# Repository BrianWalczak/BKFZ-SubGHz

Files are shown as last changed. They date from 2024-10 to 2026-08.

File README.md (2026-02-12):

<h1 align="center">BKFZ SubGHz</h1>
<p align="center">A robust program for your ESP32 to capture and replay SubGHz frequencies, inspired by the Flipper Zero and written in Arduino + React Native.</p>

<p align="center">
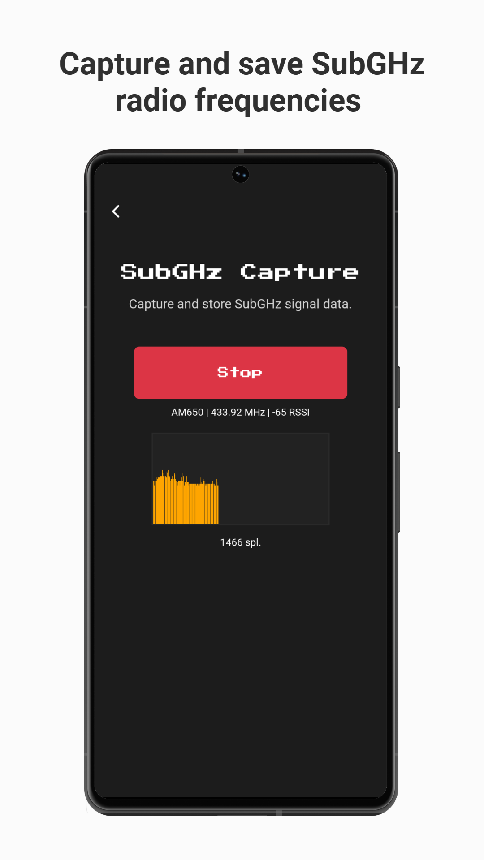
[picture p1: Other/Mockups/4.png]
  
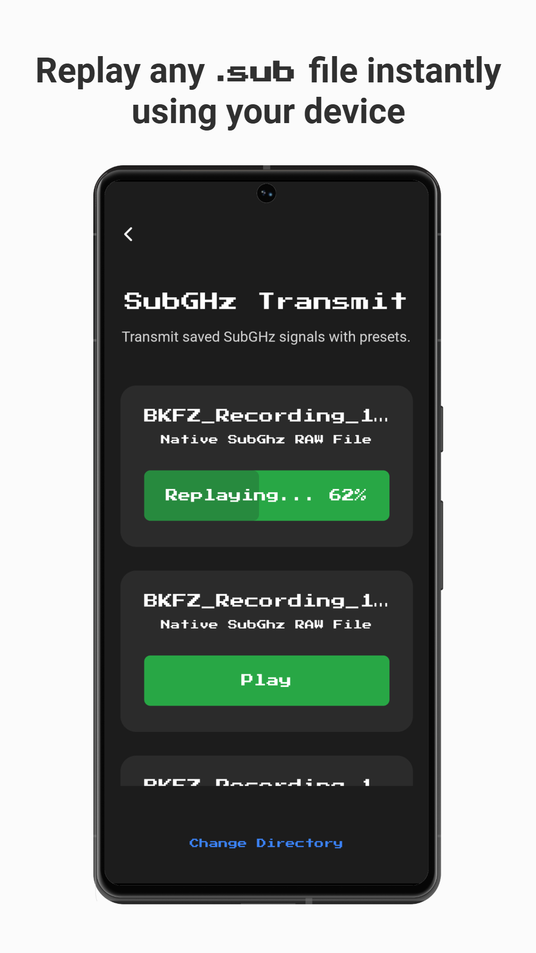
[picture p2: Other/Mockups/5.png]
  
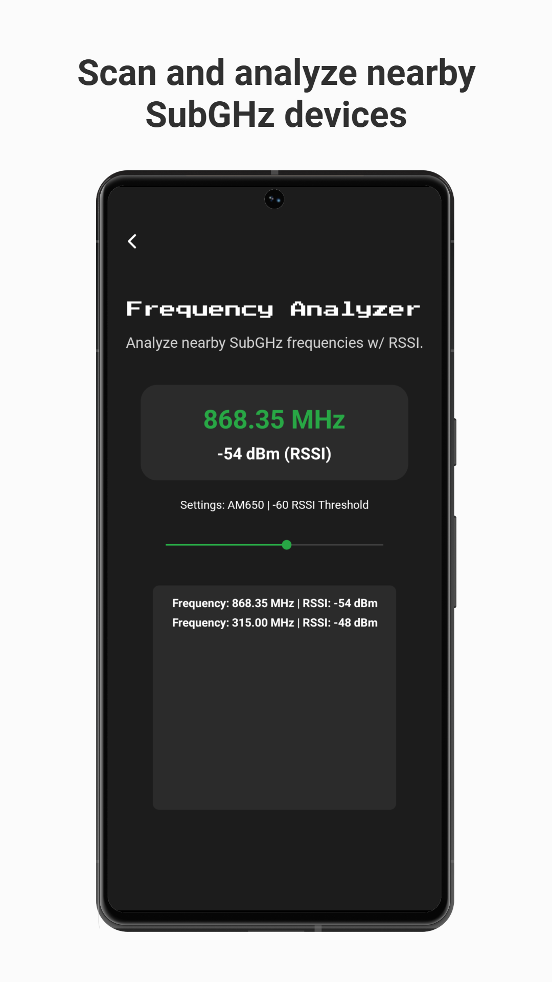
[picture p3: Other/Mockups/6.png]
  
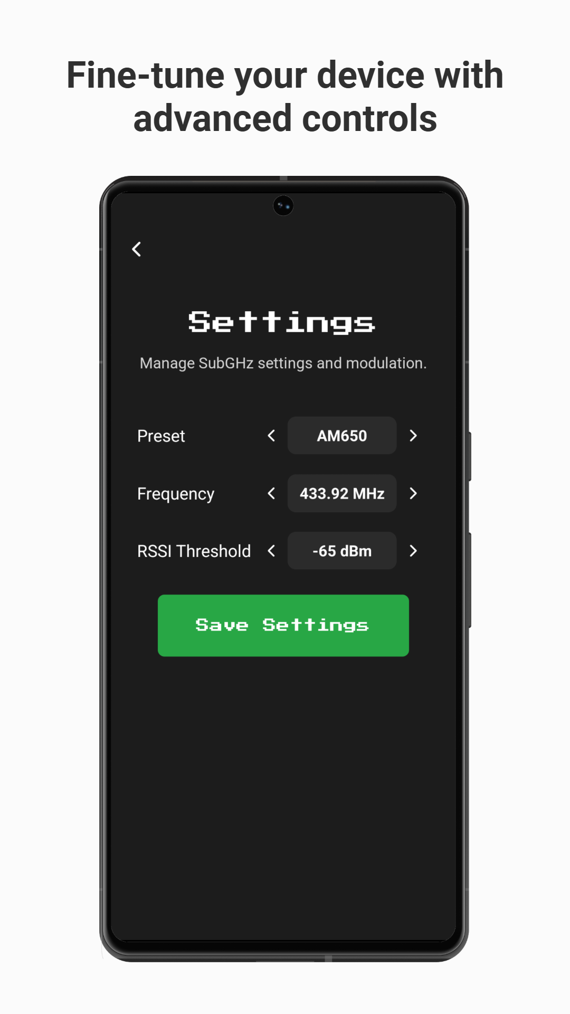
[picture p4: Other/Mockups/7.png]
  
</p>

> [!WARNING]
> **Heads up! Major changes have been made since the previous release. If you encounter any issues, please report them <a href='https://github.com/brianwalczak/BKFZ-SubGHz/issues'>here</a>.**

## Features
- (📻) **Record RAW** - Capture and save SubGHz radio frequencies with a configurable RSSI threshold (saved as `.sub`).
- (📡) **Replay/Emulate RAW** - Easily transmit SubGHz radio frequencies from file (no SD card required).
- (🔍) **Frequency Analyzer** - Scan and analyze nearby devices across multiple frequencies (300-928 MHz).
- (⚙️) **Custom Presets** - Support for various digital modulations and frequency bands with customizable presets.
- (🛜) **Wi-Fi/Bluetooth Connectivity** - Support for both Bluetooth and Wi-Fi based connectivity (web server).
    - (📱) **Mobile App** - Cross-platform mobile application for Bluetooth, powered by React Native (iOS + Android).
    - (🌐) **Web App** -  WebSocket-powered web app for Wi-Fi connectivity, works on any device with a browser.
- (🐬) **Flipper Zero Support** - Built with Flipper Zero native support, allowing you to record and play `.sub` files.
- (🔋) **Portable Design** - Custom PCB design for battery-powered operation with a compact design.
- (👤) **Open Source** Open-source under Apache 2.0 license - contribute or view it anytime.

## Requirements
To start, you'll need (by minimum) an [**ESP32**](https://s.click.aliexpress.com/e/_DCh9q31) [$2.97] of your choice and a [**CC1101 RF Transceiver**](https://s.click.aliexpress.com/e/_DlNeVmT) [$2.01]. You can purchase both of these parts in the links provided.

> [!CAUTION]
> **When choosing a CC1101 module, make sure to select the operating frequency that is most commonly used in your region. The** `433 MHz` **frequency band is generally most common, but this may vary based on the device you're attempting to emulate.<br><br>Your module can use either a [wire antenna](https://s.click.aliexpress.com/e/_DlNeVmT) or an [SMA antenna](https://s.click.aliexpress.com/e/_Dn4dKAr) — both options are compatible.**

If you're looking to build a fully-fledged BKFZ SubGHz device, you'll want to purchase these additional components (about **~$13.03**):
- [2000mAh Lithium Battery](https://s.click.aliexpress.com/e/_DnKGR3V): **$6.03** on AliExpress (**ensure your ESP32 includes a built-in voltage regulator, or attach one separately**)
- [TP4056 Module (5pk)](https://s.click.aliexpress.com/e/_Dd8V8J1): **$1.36** on AliExpress
- [Latching Buttons (10pk)](https://s.click.aliexpress.com/e/_DkSsHEL): **$1.13** on AliExpress 
- [JST 2mm Connectors (10pk)](https://s.click.aliexpress.com/e/_DCTEiy7): **$1.01** on AliExpress 
- [Custom PCB Print](https://github.com/brianwalczak/BKFZ-SubGHz/tree/main/KiCad_PCB#bkfz-subghz---kicad-pcb): **~$3.50** on JLCPCB (w/ shipping)
<br>
Assembly Parts

The custom PCB design, as found [here](https://github.com/brianwalczak/BKFZ-SubGHz/tree/main/KiCad_PCB#bkfz-subghz---kicad-pcb), is specifically designed to work with the 433 MHz module(s) linked above.

## Getting Started
To flash the BKFZ SubGHz program on your ESP32, you'll need to connect the CC1101 module first. By default, the following pinout is used:
| ESP32 | CC1101 |
|---|---|
| GND | GND |
| 3.3V | VCC |
| G5 | CSN |
| G13 | MOSI |
| G19 | MISO |
| G14 | SCK |
| G16 | GDO0 |
| G18 | GDO2 |

If you'd like to use a different pinout, you can configure the pins in the `headers/config.h` configuration file.

Additionally, **you'll need to decide which connection mode you'd like to use**. By default, your BKFZ SubGHz device will use Bluetooth Low Energy for communication with the **mobile app**. If you'd like to use Wi-Fi connectivity (or your device does not support the mobile app), you should modify the `CONNECTION_MODE` definition to `CONNECTION_MODE_WIFI` in the configuration file.

**Note:** If possible, Bluetooth connectivity is highly recommended as it's more reliable on mobile devices.

To install the BKFZ SubGHz firmware, you'll need to open this repository in Arduino IDE in the `Arduino/` folder.

---

### Wi-Fi Connection

If you've selected Wi-Fi as the connection mode, you'll need to download and install the [LittleFS Upload](https://github.com/earlephilhower/arduino-littlefs-upload) plugin (you can find instructions on installation in the repository). This plugin is crucial to serve essential files through the web server (CSS, fonts, icons, etc).

Next, you should upload the `data/` files through LittleFS (`Ctrl` + `Shift` + `P`, then `Upload LittleFS to Pico/ESP8266/ESP32`). **Make sure your Serial Monitor is closed during the uploading process.**

---

Lastly, click the `Upload` icon in the Arduino IDE to flash the code on your ESP32. All done!

## Usage
Once you've completed the firmware installation, it's time to access the interface! There are multiple ways to do this, depending on the connection mode you've selected.

### Bluetooth Connection

> [!WARNING]
> Currently, the BKFZ SubGHz mobile app must be sideloaded on your device while I work to publish it on the Google Play Store. Due to App Store restrictions, iOS devices will **always** require manual sideloading through Xcode. Please follow the instructions below to continue.

To access the user interface on a Bluetooth connection, you'll need to download the official **BKFZ SubGHz** app for iPhone or Android.

To compile the application manually, start by installing the required dependencies in this repository:
```bash
git clone https://github.com/brianwalczak/BKFZ-SubGHz.git
cd BKFZ-SubGHz/Application
npm install
```

Next, follow the instructions below based on your device's operating system:

#### iOS Devices
In order to sideload the application to your iPhone, you'll need to install Xcode [here](https://apps.apple.com/us/app/xcode/id497799835) on a Mac and login to an Apple ID (free or paid).

Next, you'll need to download Xcode Command Line Tools for compatibility with Expo:
```bash
xcode-select --install
```

Follow the instructions on your Mac to finish installation, then plug in your iOS device. To begin building the application, run this command:
```bash
npx expo run:ios --device --configuration Release
```

This process may take a few minutes, and the application will be installed to your device once complete. You may need to trust the developer on your iPhone to launch the application (`Settings > General > VPN & Device Management`, under `Developer App`).

#### Android Devices
There are two different ways you can install the BKFZ SubGHz app on your Android device.

- Visit the releases page [here](https://github.com/brianwalczak/BKFZ-SubGHz/releases) to download and install the latest pre-compiled APK.
- Plug in your Android device, then run `npx expo run:android --variant release` (you will need to install [Android SDK Platform-Tools](https://developer.android.com/tools/releases/platform-tools)).

### Wi-Fi Connection

1. Open the Wi-Fi settings on your mobile device and connect to the `BKFZ SubGHz` Wi-Fi network (remember, you can configure the SSID and password in the configuration file).
2. Open your browser and navigate to `192.168.4.1` to view the interface.
3. Click the Connect button to establish a connection with the BKFZ SubGHz device (via WebSockets).

If the page is not found, check the `Gateway` IP address of the Wi-Fi network and navigate to the IP address.

**Tip:** If you'd like to add the user interface as a web app to your home screen, you can click `Share > Add to Home Screen` in Safari for iOS, or the 3 dots in Chrome for Android.

## Credits/Authors
This project was made possible by utilizing the following dependencies:
- [`ELECHOUSE_CC1101_SRC_DRV`](https://www.arduino.cc/reference/en/libraries/smartrc-cc1101-driver-lib/) | A library for controlling the CC1101 module, which is commonly used for wireless communication in Arduino projects.
- [`ESPAsyncWebServer`](https://www.arduino.cc/reference/en/libraries/espasyncwebserver/) | A library that enables the creation of web servers on the ESP32 and ESP8266.
- [`React Native`](https://reactnative.dev/) | A popular open-source framework for building native mobile apps using React.
- [`Expo`](https://expo.dev/) | A full-stack React Native framework that makes development, testing, and deployment of apps much easier.
- [`ESP32 Core Libraries`](https://github.com/espressif/arduino-esp32/tree/master/libraries) | A collection of libraries pre-installed on the ESP32 (including Wi-Fi, SPI, LittleFS, Preferences, and much more).
- [`Flipper Zero`](https://github.com/flipperdevices/flipperzero-firmware) | This project couldn't be made possible without the extensive documentation and awesome team over at Flipper Zero ♥

These are just a couple honorable mentions; view the `package.json` and Arduino code for more details!

## FAQ

### Does this project allow me to emulate devices with iButton, NFC/RFID, or Infrared technology?
No, the BKFZ SubGHz can **not** emulate any of these types of devices, unlike the Flipper Zero. This project is specifically focused on replicating the SubGHz functionality of the Flipper Zero. However, it is theoretically possible to achieve this with an ESP32 and the appropriate module (though it's unlikely to happen).

### Do I need a paid Apple Developer account to install the app?
Nope! If you have access to Xcode, you can use a free Apple ID to sideload the app. However, you will need to re-install the application every **7 days** due to iOS restrictions, so it's recommended that you use Wi-Fi connectivity instead. Sorry!

### Do I need to have an internet connection?
You don't need internet access to use the BKFZ SubGHz, however you will need to connect to its Wi-Fi access point if you're using Wi-Fi Connection Mode (learn more [here](#wi-fi-connection-1)).

### Who is maintaining this project behind the scenes?
At the moment, this project is solely developed and maintained by me (thanks to the amazing resources [here](#creditsauthors)). That said, I highly encourage you to contribute to the project by submitting a pull request! It would be greatly appreciated.

### I found a bug or would like to submit feedback.
That's great to hear! You can submit any feedback, or any bugs that you find, on the <a href='https://github.com/brianwalczak/BKFZ-SubGHz/issues'>issues page</a>. I check these very frequently, and I highly encourage you to find bugs.

### I love this project! How can I support its maintenance?
I'm glad to hear that you find this project useful! If you'd like to support this project and its development, you can send me a tip <a href='https://ko-fi.com/brianwalczak'>here</a> 😁

<br>
  <p align="center">Made with ♡ by <a href="https://brian.re/">Briann</a></p>

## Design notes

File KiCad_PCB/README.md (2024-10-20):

# BKFZ SubGHz - KiCad PCB
A custom-designed printed circuit board designed for connecting a [Wemos D1 Mini](https://s.click.aliexpress.com/e/_DCh9q31) (ESP32), a [CC1101](https://s.click.aliexpress.com/e/_DlNeVmT) module, and a [TP4056](https://s.click.aliexpress.com/e/_Dd8V8J1) battery module (optional). This PCB was designed for the BKFZ SubGHz as an easy way to connect the components.

This PCB was designed in KiCad (you can import it with `File > Open Project` and exported as a ready-to-print Gerber file. I printed this PCB for about **$3.50** (quanity of 5) on [JLCPCB](https://jlcpcb.com/) (not sponsored).

### Assembly
> **If you'd like to see detailed photos of each step in the assembly process, you can check them out [here](https://github.com/BrianWalczak/BKFZ-SubGHz/tree/main/Other/Assembly%20Photos).**

To assemble the BKFZ SubGHz device, I began by soldering female headers onto the PCB. This allows for easy attachment and removal of the ESP32 and CC1101 (if any changes are necessary). I started by soldering female headers on the underside of the PCB, and then soldered male headers to the ESP32, pointing upward, as shown below:

ESP32 - Soldered Male Headers
PCB Design - Soldering Female Headers for the ESP32
PCB Design - Soldering Female Headers for the CC1101
<br><br>

Once this was completed, I moved on to the TP4056 module and the JST connector. I soldered the positive and negative wires from the battery to the appropriate terminals on the TP4056. Next, I soldered two smaller wires to the `OUT-` and `OUT+` terminals for the power output:

TP4056 - Parts
TP4056 - Soldered BAT
TP4056 - Soldered OUT
<br><br>

To secure the latching power button, I used double-sided tape and attached it on the side the female headers for convenience (had to get creative with it 😅). I soldered the positive wire from the TP4056 to one end of the button, and then added a red wire to the other end. The negative wire from the TP4056 was soldered directly to the negative SMD pad on the PCB, while the positive wire (from the other end of the button) was soldered to the positive SMD pad:

TP4056 Positive Wire
Latching Button (Positive)
Final Result
<br><br>

> [!TIP]
> **This button design allows the device to be powered on and off, helping to preserve battery life and prevent interference with other devices.**

Finally, I connected the battery to the JST connector, and that's it! We've successfully built our own BKFZ SubGHz device.

Final Result w/ Battery

### Photos
This project utilized the Wemos D1 Mini symbol and footprint by [@r0oland](https://github.com/r0oland/ESP32_mini_KiCad_Library), as well as the TP4056 battery module footprint by [@ccadic](https://github.com/ccadic/TP4056-18650). The CC1101 symbol and footprint was designed by me, as I was unable to find it online anywhere.

#### Schematic
Schematic

#### PCB Design
PCB Design
<br><br>

**If you'd like to see detailed photos of each step in the assembly process, you can check them out [here](https://github.com/BrianWalczak/BKFZ-SubGHz/tree/main/Other/Assembly%20Photos).**

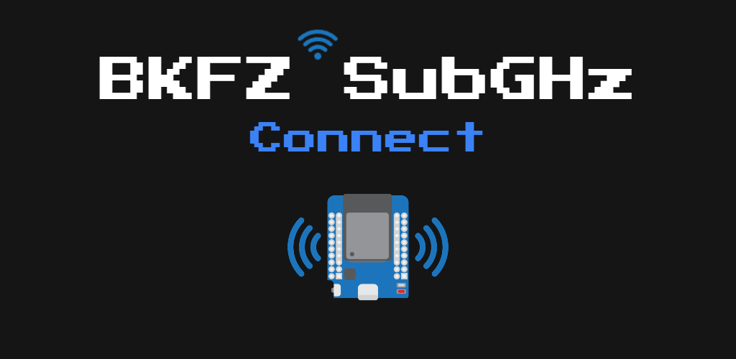
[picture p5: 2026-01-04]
Other/Mockups/feature_graphic.png

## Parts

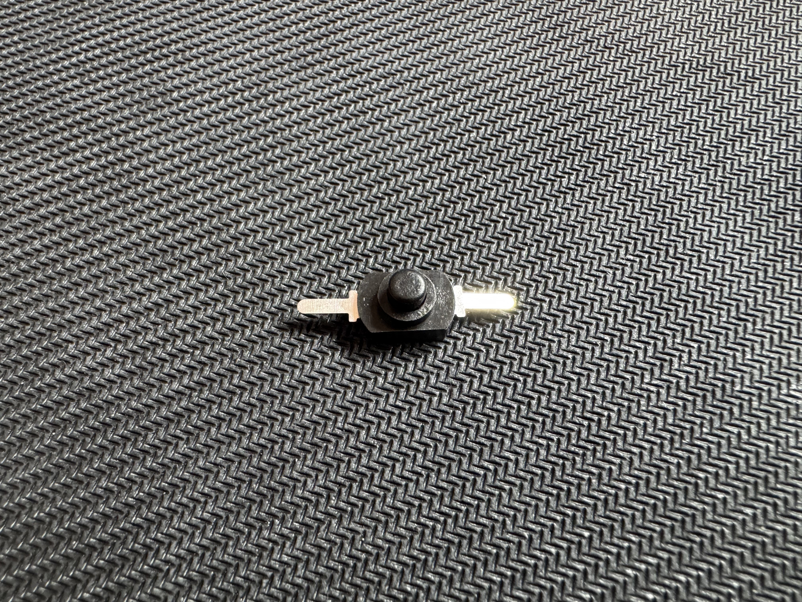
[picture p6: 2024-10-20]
Other/Assembly Photos/Components/Latching Button (I-O).jpeg

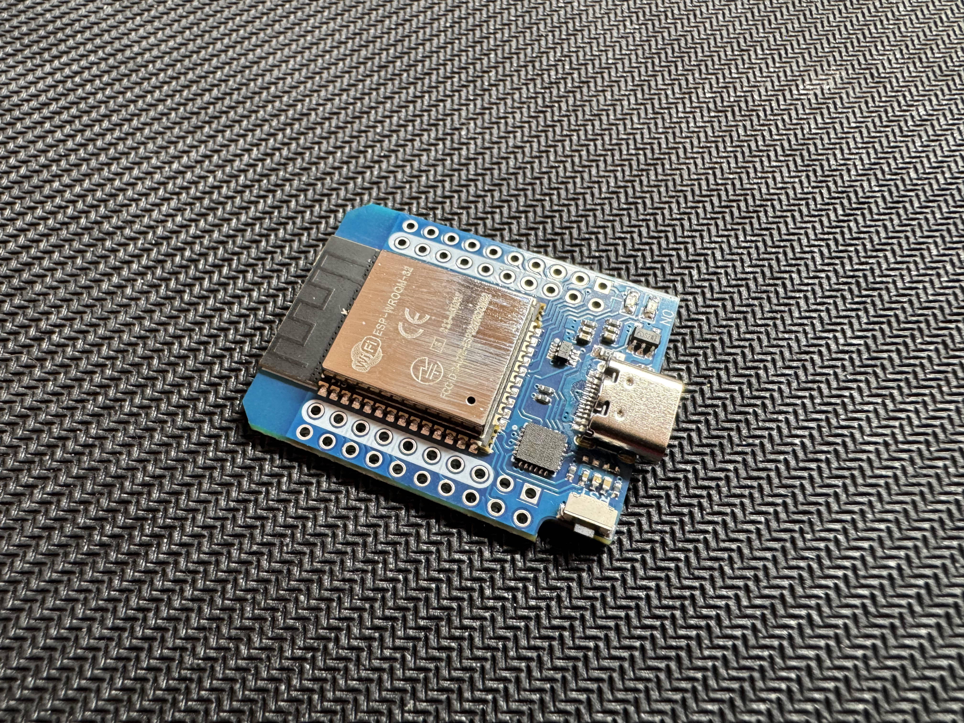
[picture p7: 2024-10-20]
Other/Assembly Photos/Components/ESP32 D1 Mini.jpeg

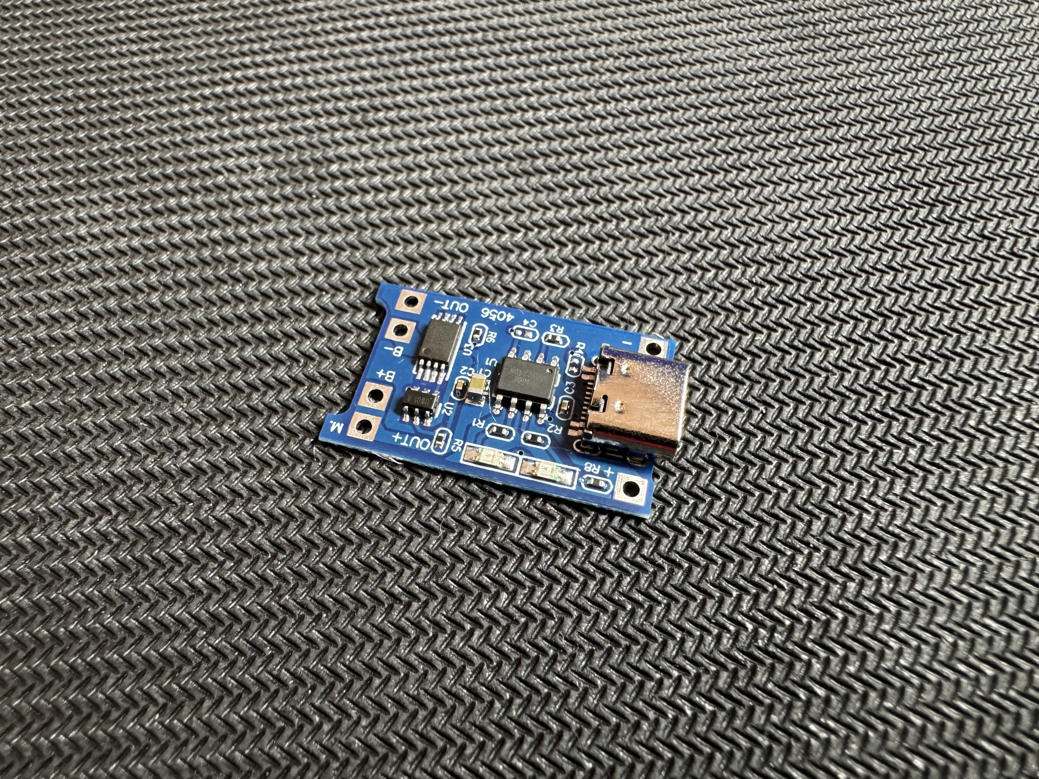
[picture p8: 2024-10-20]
Other/Assembly Photos/Components/TP4056 Module.jpeg

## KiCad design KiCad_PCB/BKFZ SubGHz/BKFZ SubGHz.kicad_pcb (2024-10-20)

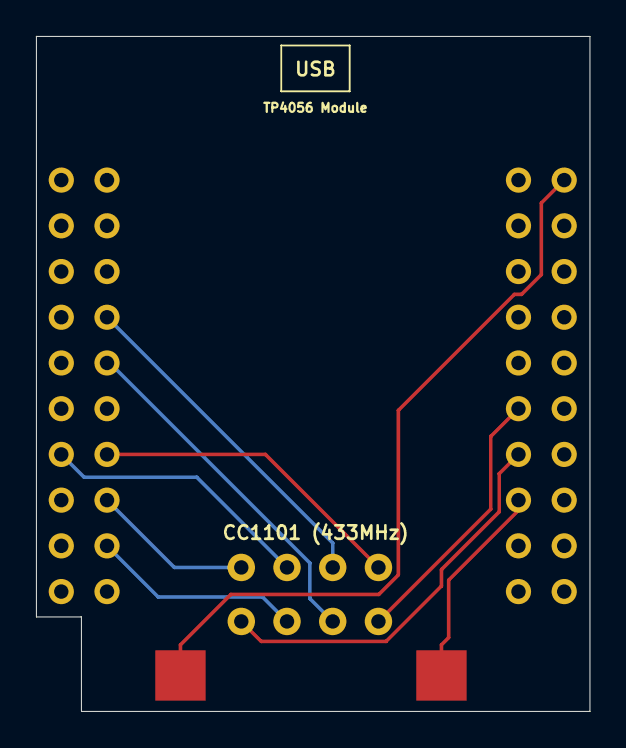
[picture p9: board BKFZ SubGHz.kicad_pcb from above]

Board: 2 copper layers, 30.8 x 37.5 mm, 3 parts (0 on the bottom side), 6 nets.

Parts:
CC1101_433MHz1: CC1101_SubGHz
ESP32_D1_Mini1: ESP32_Mini
TP4056_18650: TP4056_18650

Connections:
unnamed: CC1101_433MHz1.5 (GND), ESP32_D1_Mini1.33 (GND)
unnamed: CC1101_433MHz1.6 (MOSI), ESP32_D1_Mini1.18 (IO_13/TCK)
unnamed: CC1101_433MHz1.2 (SCK), ESP32_D1_Mini1.13 (IO_14/TMS)
unnamed: CC1101_433MHz1.1 (VCC), ESP32_D1_Mini1.16 (3V3)
unnamed: ESP32_D1_Mini1.35 (VCC_(USB)), TP4056_18650.3 (OUT+)
unnamed: ESP32_D1_Mini1.22 (GND), TP4056_18650.4 (OUT-)

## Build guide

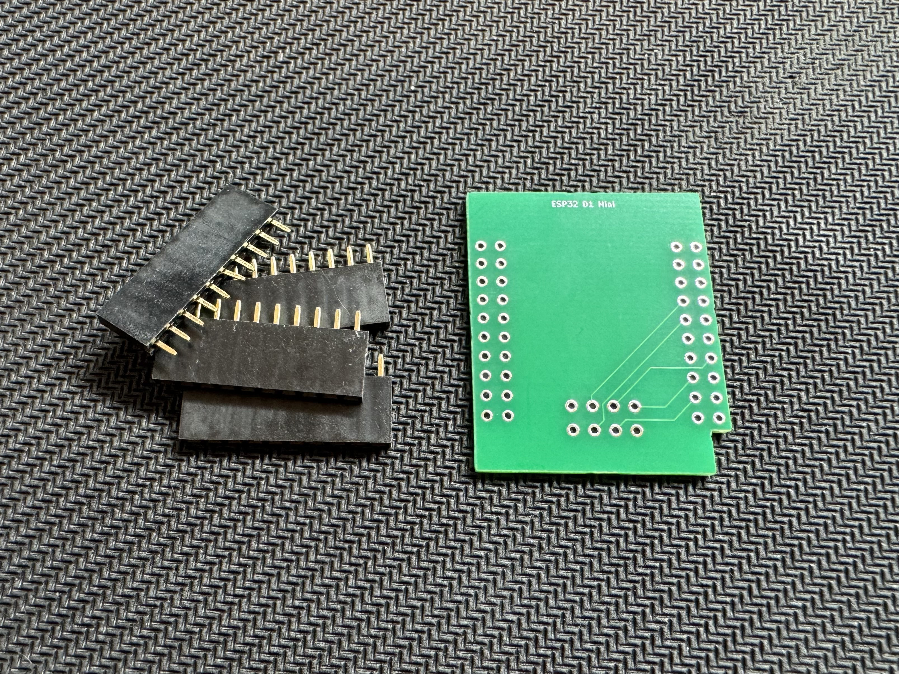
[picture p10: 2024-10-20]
Other/Assembly Photos/Step 1. Soldering to PCB (before).jpeg

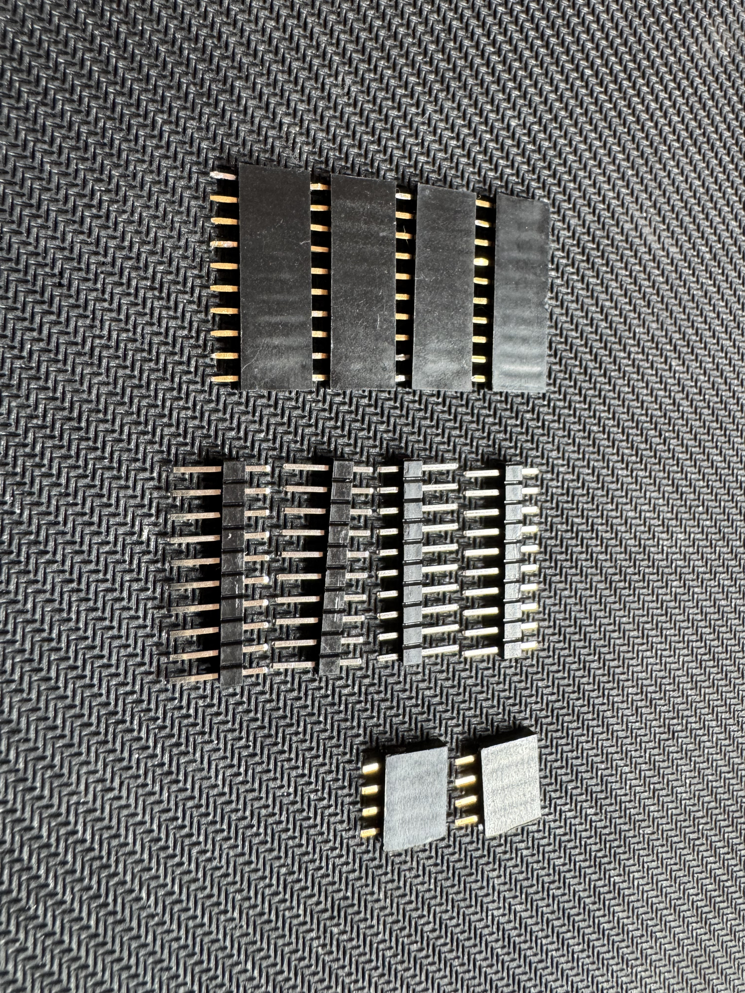
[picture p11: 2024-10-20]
Other/Assembly Photos/Components/Headers (to solder).jpeg

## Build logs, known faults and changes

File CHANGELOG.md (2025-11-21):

# Changelog | BKFZ SubGHz

## Roadmap

- [x] Create an app using React Native
  - [x] Welcome Page
  - [x] Connect Device
  - [x] Home Page
  - [x] Record Page
  - [x] Play Page
  - [x] Settings Page
  - [x] Frequency Analyzer
- [x] Add Bluetooth transmission for app compatibility
- [x] Update presets to better match Flipper Zero
- [x] Fix configuration file structures
- [x] Add an option for no RSSI threshold
- [x] Remove JSON and create custom protocol
- [x] Fix page animation to use back motion properly
- [x] Test functionality on iOS devices, make changes
- [x] Create new revamped icons and assets
- [x] Minor code reconstruction to minimize memory usage
- [x] Make improvements for WiFi-based connection (`.html` pages)
- [x] Update `README.md` to improve instructions and clarity

---

## 📱 App Demo (Bluetooth)

https://github.com/user-attachments/assets/3f9ae117-1401-43c5-9235-534f86dca0eb

## 🌐 Web Demo (WiFi / Access Point)

https://github.com/user-attachments/assets/d5fcab91-d8fd-4988-91c3-9640dd40cf5b

---

## Timeline

### 11/20/2025
- Improve `README.md` instructions, publish release!

### 11/19/2025
- Added support for **Press Start 2P** font on web platform
- Added command events for WebSocket data in `wifi_interface.cpp`
- Patched minor bugs for sending / receiving data with WebSockets
- Added web compatibility for `record.tsx` (update download logic)
- Removed unnecessary functions, phased out `ArduinoJson` from project
- Uploaded initial build of React web app w/ `gzip` compression
- Created connection timeout for WebSockets (`Promise`)
- Added an unexpected disconnect warning message
- Improved clarity across `Serial.println` messages
- Updated message popup logic, and included fade animation
- Quick commit to set Bluetooth as default connection mode
- Fixed critical bug with disabled RSSI threshold

### 11/18/2025
- Created `gzip` compression helper for web exports (brotli not supported on HTTP!)
- Started rebuilding `wifi_interface.cpp`, added static file serving
- Fixed back navigation logic for multi-platform support
- Removed connect page for web platform, created custom `index.tsx` w/ connectivity
- Created other minor improvements / fixes

### 11/17/2025
- Modified array declarations to minimize memory usage
- Fixed comments throughout code for clarity
- Migrated to `expo-document-picker` for web compatibility
- Updated file reading to handle both native and web platforms
- Created separate `GlobalContext.tsx` for native and web platforms
- Started WebSocket implementation in global context
- Created a connect page for web platform
- Updated imports for `@expo/vector-icons` to reduce storage size
- Replaced **Ionicons** and Bluetooth from **MaterialIcons** to **Feather** instead

### 11/14/2025
- Fix bugs and type safety for settings, add null checks
- Remove unused dependencies from `package.json`

### 11/13/2025
- Updated code to properly update settings values
- Fixed mobile app to update settings locally
- Remove unused imports, fix dependency arrays
- Fix Bluetooth scanning with new refactored API

### 11/12/2025
- Added builder methods to send data in mobile app
- Simplified data buffer storage in mobile app
- Removed JSON from code, updated to read binary packets

### 11/11/2025
- Removed status and settings options JSON injection
- Updated mobile app to use new data parser
- Fixed minor bug with settings data
- Fixed critical bug for samples and graphing data (remove `memcpy`)
- Moved `.sub` file creation to be handled client-side
- Made small adjustment to preset max length

### 11/10/2025
- Updated mobile app font to Roboto
- Created new protocol structure in `packets.h`
- Updated methods to send data w/ binary protocol
- Added parser methods for incoming data in mobile app

### 11/05/2025
- Created play page w/ file reading utility, fixed typos
- Added progress percentage display when playing files
- Added smooth button progress bar w/ animation
- Added Bluetooth compatibility for `react-native-permissions`
- Created global toast message and included in layout
- Updated to show welome page by default (fixed page direction)
- Created custom icon, favicon, and splash for mobile app
- Added loader for settings before the page is accessible
- Fixed package versions for compatibility

### 11/04/2025
- Removed unnecessary / deprecated permissions
- Added truncation of text to prevent new lines
- Update Bluetooth permission check for iOS
- Minor UI improvements for connection page
- Added stopped scanning listener to prevent interruptions
- Updated Bluetooth scanning to lower interval for precision
- Clear devices list on disconnect (clear stale results)
- Added global back arrow component for page navigation
- Tested all functionality on iOS devices

### 11/03/2025
- Created settings page with global update logic
- Fixed `detect_rssi` to update locally on changes
- Added async storage to check for new users
- Created welcome page, display for new users
- Added back arrow in connection page
- Created design in **Adobe Illustrator** for welcome page
- Removed faulty dependency for iOS (failed compilation)
- Added and fixed iOS permissions w/ descriptions

### 10/30/2025
- Created record page w/ file saving implementation
- Created utils.ts for shared functions
- Cleaned up event registering logic for Bluetooth
- Checks for device settings upon connection
- Created frequency analyzer page
- Fix frequency analyzer to check for no values

### 10/29/2025
- Used larger MTU for faster data transmission
- Fixed MTU negotiation for iOS devices
- Minor bug fixes for record page (HTML)
- Added Bluetooth data events to register via pages

### 10/28/2025
- Migrated to LittleFS for better compatibility
- Added simple Bluetooth data logic (notifications)
- Created function to send data via Bluetooth
- Add end markers for writing data, parsed end marker for receiving data
- Added Bluetooth interface logic and marker checking (Arduino)

### 10/27/2025
- Moved device connection logic to global context
- Added functions for use across pages (BLE)
- Listening for connect/disconnect events
- Add automatic page switching on connection
- Check for existing connections w/ name filtering
- Created home page upon connection
- Move header definitions, create Wi-Fi interface, re-structure (Arduino)
- Created functions to be used across files (Arduino)
- Defined globals.h (mainly used by interfaces)
- Added navigation logic for home page

### 10/26/2025
- Created initial commit for mobile app
- Created a simple warning/error screen
- Added simple Bluetooth logic w/ connection (global context)
- Check for permissions before connection attempts (polling)
- Created UI for displaying Bluetooth devices

### 10/25/2025
- Cleanup code structure
- Added SubGHz recording improvements
- Fixed frequency analyzer bug with listening for data
- Added option for no RSSI threshold
- Updated presets data to better match Flipper Zero
- Simple graphing logic updates client-side (web)

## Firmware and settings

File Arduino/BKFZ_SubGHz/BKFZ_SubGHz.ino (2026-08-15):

#include <ELECHOUSE_CC1101_SRC_DRV.h>
#include <esp_attr.h>
#include <Arduino.h>
#include <SPI.h>
#include <climits>

#include "headers/config.h"
#include "headers/presets.h"
#include "headers/user_settings.h"
#include "headers/interface.h"
#include "headers/globals.h"
#include "headers/packets.h"

int16_t samples[MAX_SAMPLES];
volatile int sampleIndex = 0;
volatile unsigned long lastTime = 0;

int16_t itemsToGraph[1024];
bool graphUpdateNeeded = false;
volatile int graphSkipped = 0;
volatile int graphIndex = -1;
volatile int lastSend = 0;

// Updates the settings for the CC1101 (utilizes user settings)
void setupCC1101(bool transmit, int retry = false) {
  ELECHOUSE_cc1101.setSpiPin(SCK_CPIN, MISO_CPIN, MOSI_CPIN, CSN_CPIN);
  ELECHOUSE_cc1101.Init();
  ELECHOUSE_cc1101.setMHZ(settings.frequency / 1000000.0);

  if(transmit) {
    pinMode(GDO0_CPIN, OUTPUT);
    ELECHOUSE_cc1101.SetTx(); // Enables transmit mode (used for sending)
  } else {
    pinMode(GDO2_CPIN, INPUT);
    ELECHOUSE_cc1101.SetRx(); // Enables receive mode (used for listening)
  }

  const Preset* preset = findPreset(settings.preset);
  if (preset == nullptr) {
    Serial.println(F("[CC1101]: Unknown preset configured, falling back to default (AM650)."));
    preset = findPreset("AM650");
  }
  applyConfiguration(preset->data, preset->length);
  
  if(!ELECHOUSE_cc1101.getCC1101()) {
    if(!retry) {
      Serial.println(F("Connection failed with CC1101 module, attempting to reconnect..."));
      setupCC1101(transmit, true);
    } else {
      Serial.println(F("Connection retry failed. Please check your wiring and pin configuration to the CC1101 module."));
    }
  }
}

// Enables receiver mode and records RAW samples
void startRecording() {
  setupCC1101(false); // Initialize CC1101 with receiver mode
  status.record = "RUNNING";
  
  // Update all of the pins and setup interrupt
  flushSamples();
  attachInterrupt(digitalPinToInterrupt(GDO2_CPIN), onSignalChange, CHANGE);
}

// Stops recording and checks if successful
void stopRecording() {
  detachInterrupt(digitalPinToInterrupt(GDO2_CPIN));
  status.record = "IDLE";
}

// Captures and analyzes nearby frequencies w/ RSSI
void frequencyAnalyzer() {
  status.detect = "RUNNING";
  Serial.println(F("[ANALYZER]: Started frequency analyzer..."));

  // Store old settings to revert when done and last seen frequency / RSSI
  int old_freq = settings.frequency;
  int lastFrequency = 0;
  int lastRSSI = 0;

  while(status.detect == "RUNNING") {
    int highestRssi = INT_MIN;
    int strongestFreq = 0;

    for(int frequency : hopperFrequenciesUSA) {
      settings.frequency = frequency; // Update to hopper frequency
      setupCC1101(false);

      int rssi = ELECHOUSE_cc1101.getRssi();

      // This signal is stronger than the one before and within threshold
      if(rssi >= highestRssi && rssi >= settings.detect_rssi) {
        highestRssi = rssi;
        strongestFreq = frequency;
      }
    }

    // If the signal is unique compared to last time, send through websocket
    if(strongestFreq != lastFrequency && highestRssi != lastRSSI && (strongestFreq != 0 && highestRssi != INT_MIN)) {
      // Set the frequency to last seen (used to prevent repetition of the same signal)
      lastFrequency = strongestFreq;
      lastRSSI = highestRssi;

      AnalyzerOut pkt;
      pkt.p_len = sizeof(AnalyzerOut);
      pkt.cmd = static_cast<uint8_t>(Command::ANALYZER);

      pkt.frequency = strongestFreq;
      pkt.rssi = highestRssi;
      sendData(reinterpret_cast<uint8_t*>(&pkt), sizeof(pkt));
    }
  }

  // Revert settings back to original before
  settings.frequency = old_freq;
  Serial.println(F("[ANALYZER]: Stopped frequency analyzer."));
}

// Play a signal from client-side file
void playSignal(const int16_t reqSamples[], uint16_t reqLength) {
  Serial.println(F("[PLAY]: Transmitting signal samples (TX)..."));
  setupCC1101(true);

  for (uint16_t i = 0; i < reqLength; i++) {
    if (reqSamples[i] > 0) {
      digitalWrite(GDO0_CPIN, HIGH);
    } else {
      digitalWrite(GDO0_CPIN, LOW);
    }

    delayMicroseconds(abs(reqSamples[i]));
  }
}

// Smoothens out the RAW samples to correct format (written with generative AI)
void smoothenSamples() {
  #define signalstorage 10

  if (sampleIndex <= 1) return; // nothing meaningful recorded, avoid read

  // Initialize variables for signal storage, counts, and sums
  int signalanz = 0;
  int timingdelay[signalstorage];
  long signaltimings[signalstorage * 2];
  int signaltimingscount[signalstorage];
  long signaltimingssum[signalstorage];

  // Initialize signal timings with default values
  for (int i = 0; i < signalstorage; i++) {
    signaltimings[i * 2] = 100000;  // Minimum timing
    signaltimings[i * 2 + 1] = 0;   // Maximum timing
    signaltimingscount[i] = 0;      // Count of timings in this range
    signaltimingssum[i] = 0;        // Sum of timings in this range
  }

  // Group signals into timing ranges
  for (int p = 0; p < signalstorage; p++) {
    for (int i = 1; i < sampleIndex; i++) {
      // Find the minimum timing for the group
      if (p == 0) {
        if (samples[i] < signaltimings[p * 2]) {
          signaltimings[p * 2] = samples[i];
        }
      } else {
        if (samples[i] < signaltimings[p * 2] && samples[i] > signaltimings[p * 2 - 1]) {
          signaltimings[p * 2] = samples[i];
        }
      }
    }

    // Find the maximum timing for the group
    for (int i = 1; i < sampleIndex; i++) {
      if (samples[i] < signaltimings[p * 2] + ERROR_TOLERANCE && samples[i] > signaltimings[p * 2 + 1]) {
        signaltimings[p * 2 + 1] = samples[i];
      }
    }

    // Count how many samples fall into this timing range and sum their values
    for (int i = 1; i < sampleIndex; i++) {
      if (samples[i] >= signaltimings[p * 2] && samples[i] <= signaltimings[p * 2 + 1]) {
        signaltimingscount[p]++;
        signaltimingssum[p] += samples[i];
      }
    }
  }

  // Determine how many signal groups are active
  signalanz = signalstorage;
  for (int i = 0; i < signalstorage; i++) {
    if (signaltimingscount[i] == 0) {
      signalanz = i;
      break;
    }
  }

  // Sort signal groups by count (from most frequent to least frequent)
  for (int s = 1; s < signalanz; s++) {
    for (int i = 0; i < signalanz - s; i++) {
      if (signaltimingscount[i] < signaltimingscount[i + 1]) {
        // Swap the signal group data
        int temp1 = signaltimings[i * 2];
        int temp2 = signaltimings[i * 2 + 1];
        int temp3 = signaltimingssum[i];
        int temp4 = signaltimingscount[i];

        signaltimings[i * 2] = signaltimings[(i + 1) * 2];
        signaltimings[i * 2 + 1] = signaltimings[(i + 1) * 2 + 1];
        signaltimingssum[i] = signaltimingssum[i + 1];
        signaltimingscount[i] = signaltimingscount[i + 1];

        signaltimings[(i + 1) * 2] = temp1;
        signaltimings[(i + 1) * 2 + 1] = temp2;
        signaltimingssum[i + 1] = temp3;
        signaltimingscount[i + 1] = temp4;
      }
    }
  }

  // Calculate average timing for each group
  for (int i = 0; i < signalanz; i++) {
    timingdelay[i] = signaltimingssum[i] / signaltimingscount[i];
  }

  // Correct raw data based on timing groups and assign high/low values
  bool lastbin = false;  // Tracks whether the last bin was high (false = low, true = high)
  int smoothCount = 0;

  for (int i = 1; i < sampleIndex; i++) {
    float r = (float)samples[i] / timingdelay[0];
    int calculate = r;
    r = r - calculate;
    r *= 10;
    if (r >= 5) {
      calculate += 1;
    }

    if (calculate > 0) {
      // Toggle the bin state between high and low
      lastbin = !lastbin;

      // Assign positive for high and negative for low
      samples[smoothCount] = (lastbin ? 1 : -1) * (calculate * timingdelay[0]);
      smoothCount++;
    }
  }

  // update sample index to ignore stale data
  sampleIndex = smoothCount;
}

// Flushes all recorded samples and resets variables
void flushSamples() {
  int oldHeap = ESP.getFreeHeap();
  int oldStack = uxTaskGetStackHighWaterMark(NULL) * sizeof(StackType_t);

  memset(samples, 0, sizeof(samples)); // flush sample array
  sampleIndex = 0;
  lastTime = 0;
  
  // reset graph variables
  memset(itemsToGraph, 0, sizeof(itemsToGraph));
  graphUpdateNeeded = false;
  graphSkipped = 0;
  graphIndex = -1;
  lastSend = 0;

  int newHeap = ESP.getFreeHeap();
  int newStack = uxTaskGetStackHighWaterMark(NULL) * sizeof(StackType_t);
  Serial.println("[FLUSH]: sample flush success, " + String(newHeap - oldHeap) + " heap regained + " + String(newStack - oldStack) + " stack regained.");
}

// Checks if graph needs to be updated (and sends data)
void checkGraph() {
  if(micros() - lastSend > 100000 && graphIndex >= 1) { // last update >100ms ago
    lastSend = micros();

    // get packet size, allocate buffer
    const size_t packetSize = sizeof(GraphOut) + (graphIndex * sizeof(int16_t));
    uint8_t* buffer = (uint8_t*)malloc(packetSize);
    if (!buffer) return;

    GraphOut* pkt = reinterpret_cast<GraphOut*>(buffer);
    pkt -> p_len = packetSize;
    pkt -> cmd = static_cast<uint8_t>(Command::GRAPH);

    pkt -> length = sampleIndex;
    for(int i = 0; i < graphIndex; i++) pkt->values[i] = (int16_t)itemsToGraph[i];
    sendData(buffer, packetSize);

    free(buffer); // clean up buffer
    memset(itemsToGraph, 0, sizeof(itemsToGraph));
    graphIndex = 0;
  }
}

// Handle event changes of CC1101
void onSignalChange() {
  const unsigned long time = micros();
  const unsigned int duration = time - lastTime;
  int rssi = ELECHOUSE_cc1101.getRssi();

  if (sampleIndex < MAX_SAMPLES && (rssi >= settings.rssi || settings.rssi == 1)) {
    samples[sampleIndex++] = duration;

    graphSkipped++;

    if(graphSkipped >= 10) {
      itemsToGraph[graphIndex++] = rssi;
      graphSkipped = 0;
    }

    graphUpdateNeeded = true;
  }

  lastTime = time;
}

void setup() {
  Serial.begin(9600);
  delay(500);
  while (!Serial) { ; }

  loadSettings();
  setupDevice();
  setupCC1101(false);
}

void loop() {
  if(status.detect == "QUEUED") {
    frequencyAnalyzer();
  }

  if(graphUpdateNeeded == true) {
    graphUpdateNeeded = false;

    checkGraph();
  }
}

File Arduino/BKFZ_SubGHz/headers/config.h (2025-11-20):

#ifndef CONFIG_H
#define CONFIG_H

#define CONNECTION_MODE_WIFI 1
#define CONNECTION_MODE_BLE  2

/* 
----- ESP32 to CC1101 -----
  GND connects to GND
  
  3.3V connects to VCC
  G5 connects to CSN/SS
  G13 connects to SI/MOSI 
  G19 connects to SO/MISO
  G14 connects to SCK
  G16 connects to GDO0
  G18 connects to GDO2
*/

/* CC1101 Pin Configuration */
constexpr int MISO_CPIN = 19;
constexpr int MOSI_CPIN = 13;
constexpr int SCK_CPIN  = 14;
constexpr int CSN_CPIN  = 5;
constexpr int GDO0_CPIN = 16;
constexpr int GDO2_CPIN = 18;

/* Recording Parameters */
constexpr int MAX_SAMPLES = 8000;
constexpr int ERROR_TOLERANCE = 200;

// Choose a connection mode ("WIFI" or "BLE")
#define CONNECTION_MODE CONNECTION_MODE_BLE

/* WiFi Configuration */
constexpr const char* ssid = "BKFZ SubGHz"; // Set an SSID for the access point
constexpr const char* password = ""; // Set a password for the access point (optional)
constexpr int SERVER_PORT = 80; // Set the desired port for the web interface

/* Bluetooth Configuration */
constexpr const char* DEVICE_NAME = "BKFZ SubGHz"; // Set the bluetooth device name

#endif

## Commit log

2024-09-21 Insert documentation
    This commit includes simple documentation to setting up your own BKFZ SubGHz device. This also includes the Apache License for this project.
2024-09-21 Create PCB directory
    This commit includes the instructions for printing and connecting the custom PCB, specially designed for the BKFZ SubGHz!
2024-09-21 🎉 v1.0.0 | BKFZ SubGHz
    This commit includes version 1.0.0 of BKFZ SubGHz! This version is currently in its beta state, and bugs are to be expected.
    [BKFZ_SubGHz.ino, config.h]
2024-10-20 Insert compiled gerber file
2024-10-20 Insert KiCad symbol + footprint library, and schematic + PCB design
    [BKFZ SubGHz.kicad_pcb, BKFZ SubGHz.kicad_sch]
2024-10-20 Update assembly instructions w/ photos
2024-10-20 Upload assembly photos
2024-10-20 🎉 v2.0.0 | BKFZ SubGHz
    This commit includes version 2.0.0 of BKFZ SubGHz! This version is currently in its beta state, and bugs are to be expected.
    [BKFZ_SubGHz.ino]
2025-10-25 Cleanup code, add sample recording improvements, fix analyzer
    [BKFZ_SubGHz.ino]
2025-10-27 Add permissions check, scan for bluetooth devices
2025-10-27 Display bluetooth devices, fix devices logic
2025-10-27 Add device connection logic
2025-10-27 Only allow BKFZ devices w/ name
2025-10-27 Move device connection logic to global context
2025-10-27 Use device connection logic from global context
2025-10-27 Remove page switch logic
2025-10-27 Switch pages on connect/disconnect
2025-10-27 Check for existing connections, add name filtering
2025-10-27 Gray out button while connecting device
2025-10-29 Create BLE interface, add marker logic, fix includes for interfaces.
    [ble_interface.cpp, wifi_interface.cpp]
2025-10-30 Fix MTU negotiation for iOS devices
    Devices running iOS < 10 will request an MTU size of 158. Newer devices running iOS 10 will request an MTU size of 185.
    https://stackoverflow.com/questions/41977767/negotiate-ble-mtu-on-ios/42336001
    [ble_interface.cpp]
2025-10-31 Fix frequency analyzer to check for no values
    [BKFZ_SubGHz.ino]
2025-11-04 Remove unnecessary success confirmation
    We'll just assume it was successful, cause otherwise the device would be disconnected (which would just prompt re-connection in the app).
2025-11-04 Truncate device name / ID if too large
2025-11-05 Lower Bluetooth scan interval, clear devices on disconnect
2025-11-05 Clear list of devices on new scan
2025-11-05 Create universal back button, update to useRouter from useNavigation
2025-11-05 Add universal back button to all pages, use SafeAreaView.
2025-11-11 Begin working on data protocol, create basic structure
    Warning, this is currently still very experimental and is a breaking change! I'm not yet done working on this, and I'll be working on full implementation later this week.
    This is my first time doing something like this, so it'll take some time!
2025-11-12 Fix critical bug for samples + graphing
    As I mentioned, first time doing this stuff and I guess I didn't do my research lol... memcpy won't work in our case. Iterating over the data is much safer!
    [BKFZ_SubGHz.ino, ble_interface.cpp]
2025-11-12 Move SUB file creation from device to application (client-side).
2025-11-13 Add reader for byte data in Arduino code (finally remove JSON)!
    Still working on implementation for settings updates. I've merged together analyzer's detect_rssi setting with the standard settings SET command.
2025-11-14 Update settings values from data, fix settings bug!
    [ble_interface.cpp]
2025-11-17 Minor improvements to sample/graph arrays (minimize memory usage), fix comments
    [BKFZ_SubGHz.ino, ble_interface.cpp]
2025-11-18 Remove Ionicons and bluetooth from MaterialIcons, use Feather instead
2025-11-20 Add web compatibility for record.tsx, phase out ArduinoJson, other minor changes
2025-11-20 Improve troubleshooting println's to `Serial`
2025-11-20 Fix critical bug for RSSI threshold setting
    [BKFZ_SubGHz.ino]
2026-08-15 Fix subfolder `header/` includes to use quotes
    [BKFZ_SubGHz.ino, ble_interface.cpp, wifi_interface.cpp]
2026-08-15 Fix invalid preset crash, replace infinity, skip empty-sample read
    [BKFZ_SubGHz.ino]
